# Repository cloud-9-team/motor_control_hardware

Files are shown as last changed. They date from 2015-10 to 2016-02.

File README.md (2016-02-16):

# Control de motores por comunicación Wi-Fi

Este proyecto forma parte de la cátedra de **Taller de Proyecto 1**, perteneciente al segundo semestre de la carrera de Ingeniería en Computación, en la Facultad de Ingeniería de la Universidad de La Plata. 

Nuestra motivación principal es lograr el **control de motores utilizando un tipo de comunicación inalámbrica**. La elección de dicha comunicación debe ser tal que se logre una abstracción del dispositivo desde el cual se envien los comandos de control. 
A partir de estas restricciones elegimos realizar el control de motores de corriente continua mediante el uso del protocolo de comunicación inalámbrica IEEE 802.11, comúnmente conocido cómo Wi-Fi. Al poder abstraernos del dispositivo que envía los comandos, se podrá hacer uso de **smartphones**, **servidores web**, o cualquier otro tipo de dispositivo que cuente con un protocolo de comunicación Wi-Fi integrado.

### Descripción 
En este proyecto se buscará desarrollar específicamente los siguientes puntos:
 - Control de dos motores de corriente continua a través de señales PWM utilizando un H-bridge IC L293D.
 - Comunicación mediante protocolo Wi-Fi con módulo independiente ESP8266.
 - Comunicación serie entre EDU-CIAA y módulo Wi-Fi.
 - Aplicación Android para comunicación con el módulo.

Estos dos últimos ítems se encuentran alojados en el siguiente repositorio https://github.com/cloud-9-team/motor_control_firmware_apps

### Esquema de funcionamiento
El funcionamiento del vehículo será controlado por **instrucciones AT** enviadas inalámbricamente por Wi-Fi desde un smartphone, corriendo un sistema operativo Android, al módulo ESP8266. El módulo ESP8266 enviará las instrucciones por **comunicación serie** a la EDU CIAA-NXP. La EDU CIAA procesará los comandos y, en base a eso, modificará los valores correspondientes de los cuatro outputs de SCT (módulo State Controlled Timer). Las señales serán enviadas a los inputs del H-bridge IC. El H-bridge, en base a la tensión media que reciba por sus entradas, permitirá a los dos motores girar en determinado sentido y con una cierta velocidad. Los sentidos y velocidades de los motores determinarán la dirección de movimiento del vehículo.

### Herramientas de desarrollo
Para el diseño del hardware se utiliza la herramienta de diseño asistido por computadora **Kicad**, y para el desarrollo del software el plugin de la CIAA para el entorno **Eclipse**.

### Integrantes del grupo

 - Julián Ailán
 - Federico Bouche
 - Lucas Hourquebie
 - Emiliano Liotta

### Descarga de los documentos
Debes tener **Git** instalado en tu máquina para poder gestionar las descargas. La instalación de Git depende del sistema operativo que uses
 - Distribuciones de Linux: 
    - En el caso de utilizar Fedora podes utilizar **yum**:
    ```sh
    $ sudo yum install git
    ```
    - En el caso de utilizar distribuciones basadas en Debian tenés que usar **apt-get**:
    ```sh
    $ sudo apt-get install git
    ```
 - Windows: accedé a http://git-scm.com/download/win y la instalación comenzará de forma automática.
 - MacOS: del mismo modo que en Windows, accedé a http://git-scm.com/download/mac y el instalador comenzará a descargarse.

Crear o posicionarse en la carpeta donde se desea descargar el contenido e inicializarla:
```sh
$ mkdir <nombre_de_la_carpeta>
$ cd <nombre_de_la_carpeta>
$ git init
```
Luego se debe relacionar el repositorio con la carpeta donde previamente te situaste:
```sh
$ git remote add origin https://github.com/cloud-9-team/motor_control_hardware.git
```
Por último, los contenidos se descargarán a la carpeta corriendo el siguiente comando:
```sh
$ git pull origin master
```
### Version
1.1

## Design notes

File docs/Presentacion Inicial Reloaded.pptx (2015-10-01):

## Presentación de Informe Inicial

Taller de Proyecto I - E0306

Control de motores mediante comunicación Wi-Fi

Fecha: 28/09/2015 Grupo 1
Integrantes:
Ailan, Julian 515/0 Bouche, Federico 536/5
Hourquebie, Lucas 509/2 Liotta, Emiliano 501/3

## Propuesta Descripción del proyecto Dispositivos a utilizar Diagrama en bloque del sistema Explicación funcional Cronograma

Contenido

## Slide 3

Propuesta

Nuestra motivación principal es lograr el control de motores utilizando un tipo de comunicación inalámbrica. La elección de dicha comunicación debe ser tal que se logre una abstracción del dispositivo desde el cual se envien los comandos de control.
A partir de estas restricciones elegimos realizar el control de motores de corriente continua mediante el uso del protocolo de comunicación inalámbrica IEEE 802.11, comúnmente conocido cómo Wi-Fi.

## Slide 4

Objetivos

Planteamos como objetivo principal el control de dos motores de corriente continua usando una aplicación en un smartphone. Se busca que dichos motores tenga anexadas una rueda cada uno, de modo tal de simular un vehículo a control remoto.
Al poder abstraernos del dispositivo que envía los comandos, esta idea puede escalarse al uso de un servidor web para el caso en que no se cuente con un smartphone.

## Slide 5

Descripción del proyecto

- Control de dos motores de corriente continua a través de señales PWM utilizando un H-bridge IC L293D.
- Comunicación mediante protocolo Wi-Fi con módulo independiente ESP8266.
- Comunicación serie entre EDU-CIAA y módulo Wi-Fi.
- Aplicación Android para comunicación con el módulo.

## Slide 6

Dispositivos a Utilizar

DISPOSITIVO | PROVEEDOR | PRECIO
Placa EDU CIAA-NXP | Electrocomponentes S.A. | $550,00
Módulo Wi-Fi ESP8266 de Espressif | Microelectrónica | $284,00
H-bridge IC L293D de ST Microelectronics | SyC Semiconductores y Componentes | $41,49
Motores CC de 9 volts | - | -

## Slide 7

Dispositivos a Utilizar

Módulo Wi-Fi ESP8266

- Frecuencia de 80 MHz.
- Arquitectura RISC.
- Funciona bajo el protocolo IEEE 802.11 a un frecuencia de 2.4 GHz con soporte WPA/WPA2.
- Presenta módulos GPIO, I²C, ADC, SPI y PWM.
- 64 KB de RAM de instrucciones.
- RAM de 96 KBytes.
- Stack de protocolos TCP/IP integrado.
- Rango de operación desde -40°C hasta 125°C

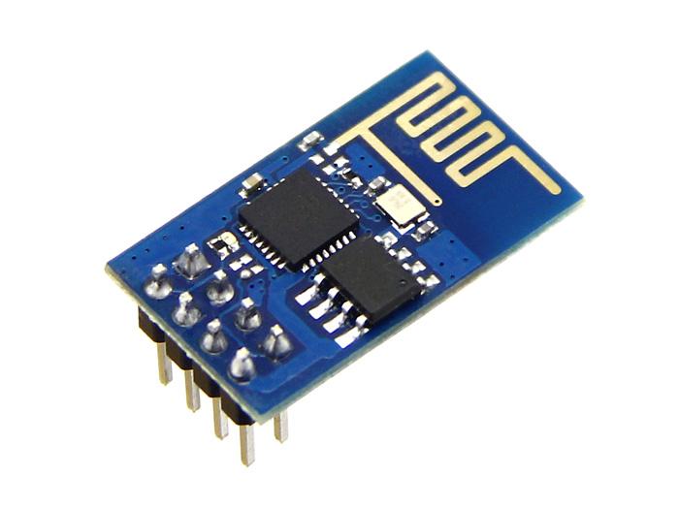
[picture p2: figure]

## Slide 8

Dispositivos a Utilizar

H-bridge IC L293D

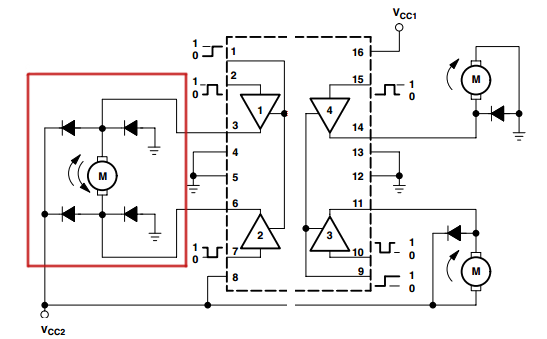
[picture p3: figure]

Configuración utilizada

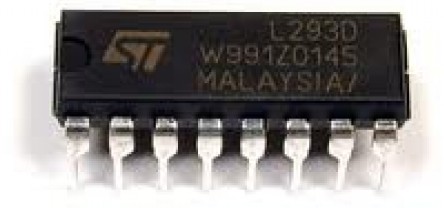
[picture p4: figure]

- Corriente de salida de 600 mA por canal (1.2 A máximo).
- Protección de sobretemperatura
- “0” lógico con tensiones hasta 1.5 V.
- “1” lógico con tensiones desde 2.3 V.
- Diodos de protección integrados.

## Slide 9

Diagrama de BLoques

L293D

ESP8266

MOTOR
1

MOTOR
2

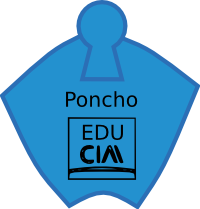
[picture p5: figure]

Transmisor

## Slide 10

Explicación funcional

- El funcionamiento del vehículo será controlado por instrucciones AT enviadas inalámbricamente por Wi-Fi desde un teléfono Android al módulo ESP8266.
- El módulo ESP8266 enviará las instrucciones por comunicación serie a la EDU CIAA-NXP.
- La CIAA procesará los comandos y, en base a eso, modificará los valores correspondientes de los cuatro outputs de SCT (módulo State Controlled Timer).
- Las señales serán enviadas a los inputs del H-bridge IC.
- El H-bridge, en base a la tensión media que reciba por sus entradas, permitirá a los dos motores girar en determinado sentido y con una cierta velocidad.
- Los sentidos y velocidades de los motores determinarán la dirección de movimiento del vehículo.

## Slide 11

Cronograma de Trabajo

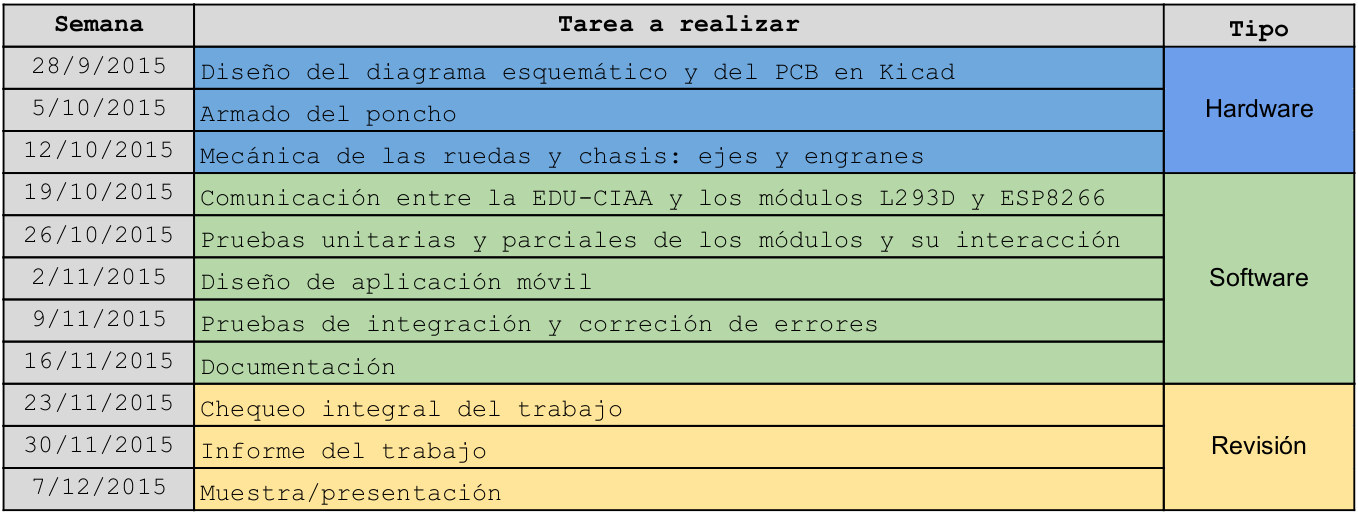
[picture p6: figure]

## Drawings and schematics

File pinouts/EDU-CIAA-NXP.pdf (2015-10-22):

# ASIGNACIÓN DE PINES

# Pernia

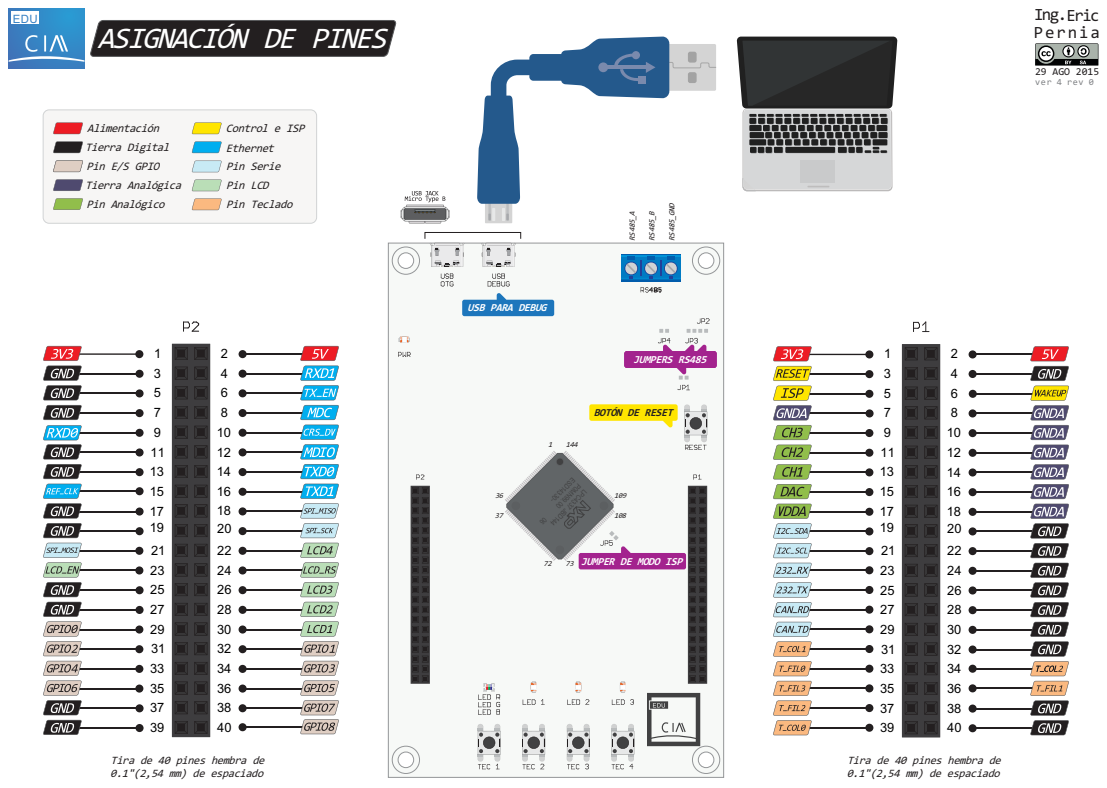
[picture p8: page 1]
Alimentación; Tierra Digital; Pin Analógico; Tierra Analógica; Pin E/S GPIO; Pin Serie; Control e ISP; Pin LCD; Pin Teclado; Ethernet; EDU; LPC4337 JBD144; ESD14330-; JUMPER DE MODO ISP; 29 AGO 2015 ver 4 rev 0; Ing.Eric; JUMPERS RS485; RS485_GND

USB PARA DEBUG

BOTÓN DE RESET

Tira de 40 pines hembra de
0.1"(2,54 mm) de espaciado

# PINES UTILIZADOS DEL NXP LPC4337 JBD144

# Pernia

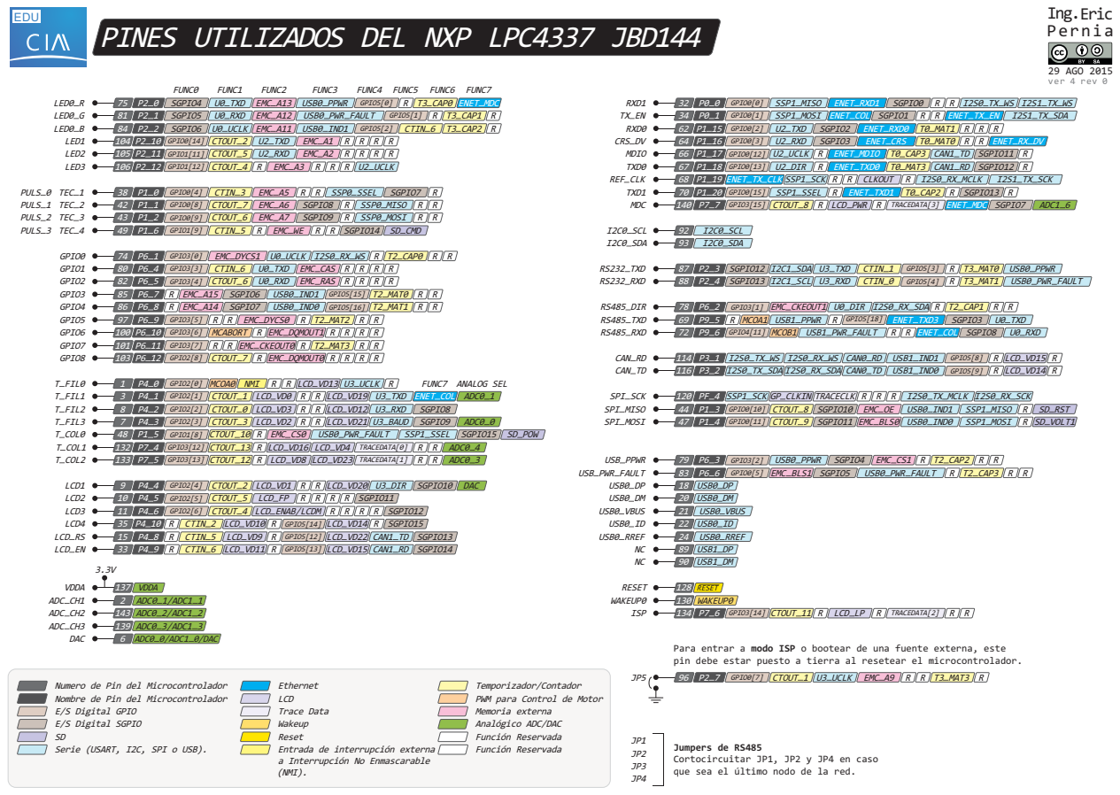
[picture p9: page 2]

Para entrar a modo ISP o bootear de una fuente externa, este
pin debe estar puesto a tierra al resetear el microcontrolador.

Numero de Pin del Microcontrolador
Nombre de Pin del Microcontrolador
E/S Digital GPIO
E/S Digital SGPIO
Serie (USART, I2C, SPI o USB).

Temporizador/Contador
PWM para Control de Motor
Memoria externa
Analógico ADC/DAC
Función Reservada

Jumpers de RS485
Cortocircuitar JP1, JP2 y JP4 en caso
que sea el último nodo de la red.

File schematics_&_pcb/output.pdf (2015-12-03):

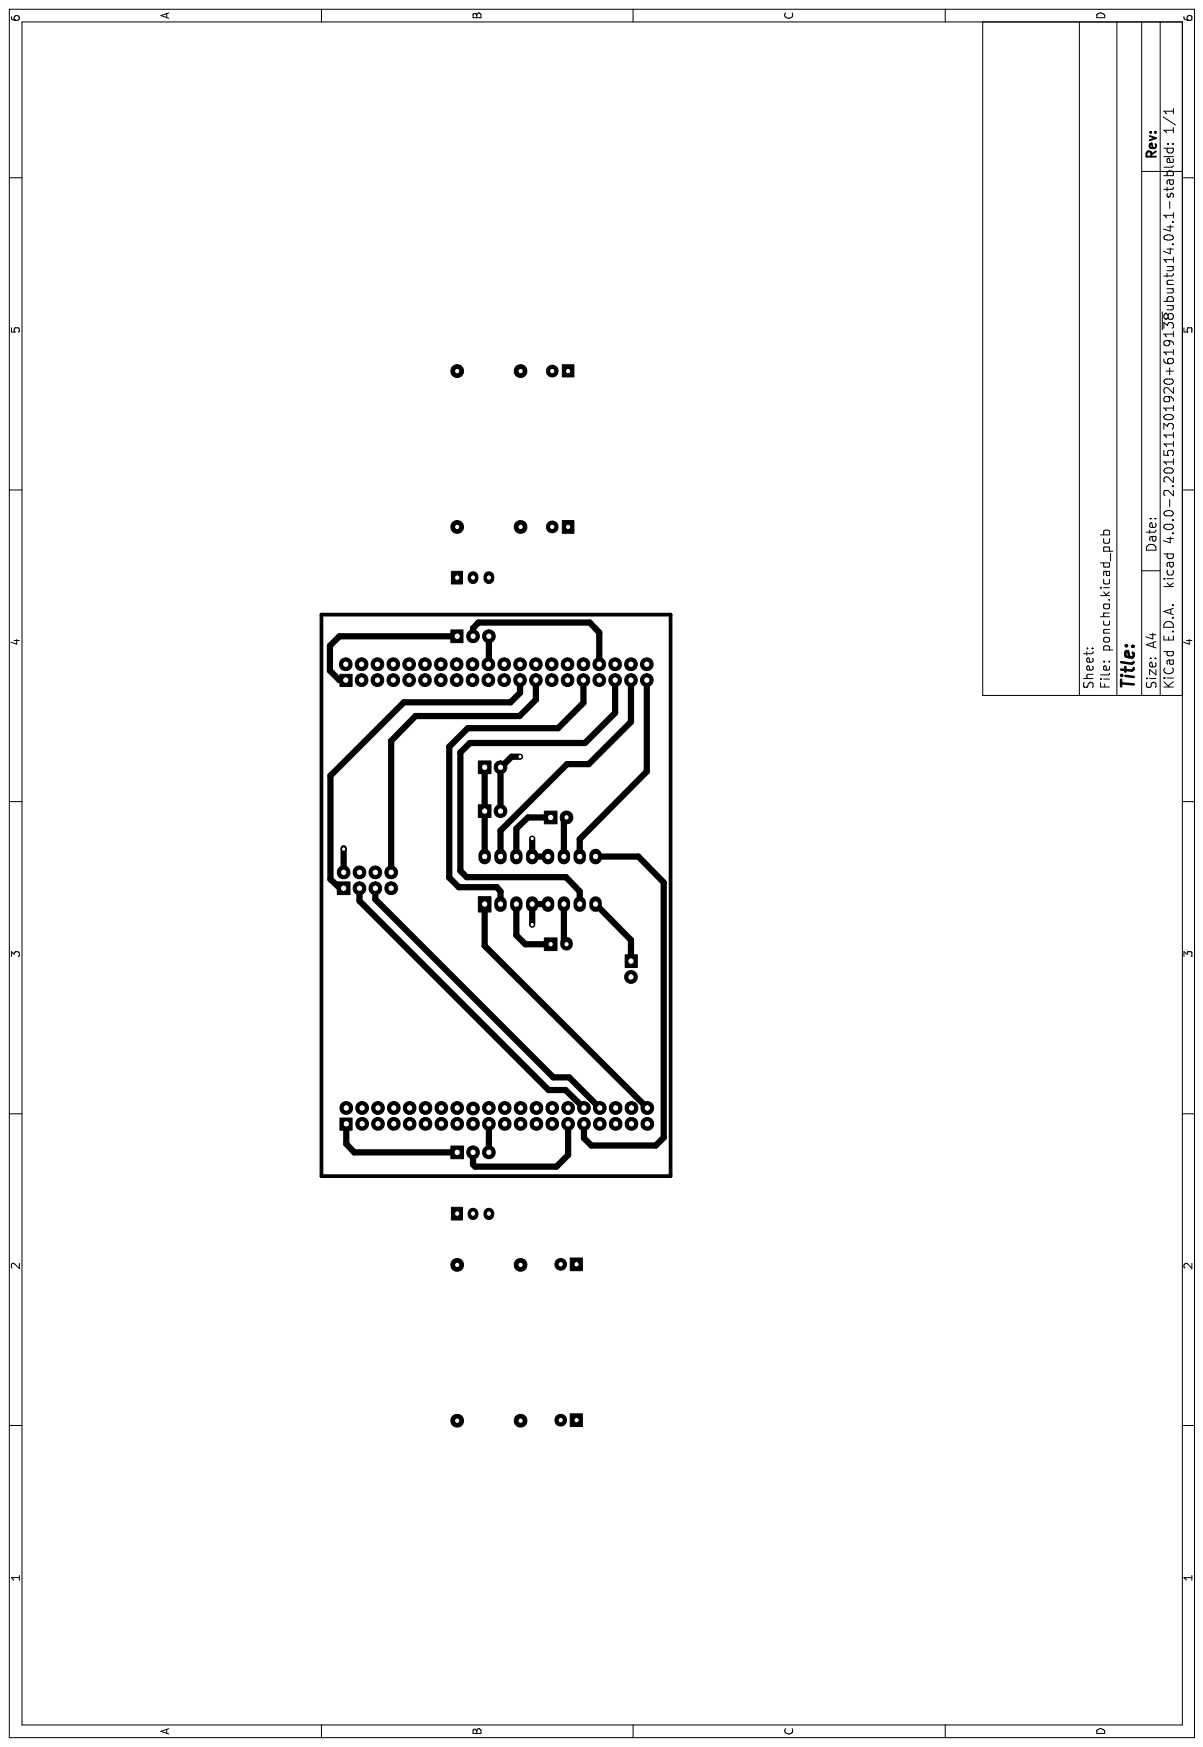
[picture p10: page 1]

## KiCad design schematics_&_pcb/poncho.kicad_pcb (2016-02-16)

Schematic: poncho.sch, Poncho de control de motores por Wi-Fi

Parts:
7805111: LM7805reg; LM7805
C1: CP; Elko_vert_11.2x6.3mm_RM2.5
C2, C3: C; C_Disc_D3_P2.5
C4: CP; c_elec_6.3x4.5
D3, D4: LED; LED-3MM
J1, J2, J3, J8, J9: TB_1X2; bornera1x2
J4, J5, J6, J7: TB_1X3; bornera1x3
L293D1: L293D; DIP-16_W7.62mm_LongPads
P1, P2: CONN_20X2; Pin_Header_Straight_2x20
P3: ESP8266; Pin_Header_Straight_2x04
R1, R4: 180; Resistor_Horizontal_RM10mm
R2, R7: 1k; Resistor_Horizontal_RM10mm
R3, R8: 680; Resistor_Horizontal_RM10mm
R5, R6: R; Resistor_Horizontal_RM10mm
SW1: 6pin_switch
TCST1, TCST2: TCST2103

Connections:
+3V3: C3.1, C4.1, J4.1, J5.1, J6.1, J7.1, P1.1, P2.1, P3.4, R1.1, R2.2, R4.1, R5.2, R7.2; also elsewhere on the board
+5V: C1.1, C2.1, L293D1.16 (VCC1), P1.2, P2.2
/ADC0_1: P1.13
/ADC0_2: P1.11
/ADC0_3: P1.9
/CAN_RD: P1.27
/CAN_TD: P1.29
/DAC: P1.15
/ENET_CRS_DV: P2.10
/ENET_MDC: P2.8
/ENET_MDIO: P2.12
/ENET_REF_CLK: P2.15
/ENET_RXD0: P2.9
/ENET_RXD1: P2.4
/ENET_TXD0: P2.14
/ENET_TXD1: P2.16
/ENET_TX_EN: P2.6
/ENG0_OUT0: J1.1, L293D1.3 (1Y)
/ENG0_OUT1: J1.2, L293D1.6 (2Y)
/ENG1_OUT0: J2.1, L293D1.14 (4Y)
/ENG1_OUT1: J2.2, L293D1.11 (3Y)
/GPIO0: J4.2, J6.2, P2.29, R3.1, TCST1.3; also elsewhere on the board
/GPIO1: P2.32, P3.2
/GPIO2: P2.31, R6.2
/GPIO3: P2.34, P3.3
/GPIO4: P2.33
/GPIO5: P2.36, P3.7
/GPIO6: L293D1.9 (3,4EN), P2.35
/GPIO7: P2.38, P3.6
/GPIO8: L293D1.1 (1,2EN), P2.40
/I2C_SCL: P1.21
/I2C_SDA: P1.19
/ISP: P1.5
/LCD1: P2.30
/LCD2: P2.28
/LCD3: P2.26
/LCD4: P2.22
/LCD_EN: P2.23
/LCD_RS: P2.24
/MOTOR_VCC: J3.1, L293D1.8 (VCC2)
/RESET: P1.3
/RS232_RXD: P1.23, P3.1
/RS232_TXD: P1.25, P3.5
/SPI_MISO: P2.18
/SPI_MOSI: P2.21
/SPI_SCK: P2.20
/TEC_COL0: L293D1.10 (3A), P1.39
/TEC_COL1: L293D1.2 (1A), P1.31
/TEC_COL2: J5.2, J7.2, P1.34, R8.1, TCST2.3
/TEC_F0: P1.33
/TEC_F1: P1.36
/TEC_F2: L293D1.15 (4A), P1.37
/TEC_F3: L293D1.7 (2A), P1.35
/VDD_A: P1.17
/WAKEUP: P1.6
GND: C1.2, C2.2, C3.2, C4.2, D3.1, D4.1, J3.2, J4.3, J5.3, J6.3, J7.3, L293D1.4 (GND1), L293D1.5 (GND2), L293D1.12 (GND4), L293D1.13 (GND3), P1.4, P1.20, P1.22, P1.24, P1.26, P1.28, P1.30, P1.32, P1.38, P1.40, P2.3, P2.5, P2.7, P2.11, P2.13, P2.17, P2.19, P2.25, P2.27, P2.37, P2.39, P3.8, TCST1.2, TCST1.4, TCST2.2, TCST2.4; also elsewhere on the board
GNDA: P1.7, P1.8, P1.10, P1.12, P1.14, P1.16, P1.18
unnamed: J8.2, J9.2
unnamed: D3.2, R5.1
unnamed: D4.2, R6.1
unnamed: J9.1, SW1.2
unnamed 66: R1.2, TCST1.1; also elsewhere on the board
unnamed 67: R2.1, R3.2; also elsewhere on the board
unnamed: R4.2, TCST2.1
unnamed: R7.1, R8.2

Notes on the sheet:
Como los encoders no formarán parte del poncho en sí, sino que se deben poner en algún lugar solidario al eje de cada motor, se deben conectar del siguiente modo: Pin #1: tensión de alimentación 3.3V, Pin #2: señal de salida, Pin #3: tierra.
Alimentación
Recepción

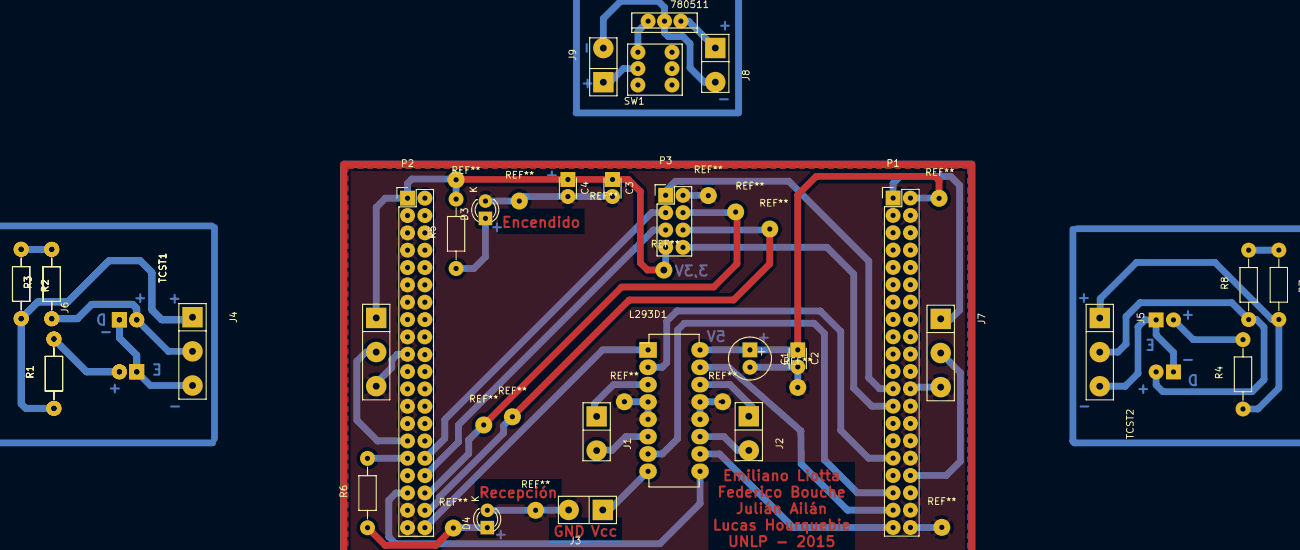
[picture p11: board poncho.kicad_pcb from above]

Board: 2 copper layers, 35 parts (0 on the bottom side), 32 nets.

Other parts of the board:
780511: LM7805reg; LM7805
R1#2: 180; Resistor_Horizontal_RM10mm
R2#2: 1k; Resistor_Horizontal_RM10mm
R3#2: 680; Resistor_Horizontal_RM10mm
TCST1#2: TCST2103

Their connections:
+3V3: R1#2.1, R2#2.2; also elsewhere on the board
/GPIO0: R3#2.1, TCST1#2.3; also elsewhere on the board
GND: TCST1#2.2, TCST1#2.4; also elsewhere on the board
unnamed 66: R1#2.2, TCST1#2.1; also elsewhere on the board
unnamed 67: R2#2.1, R3#2.2; also elsewhere on the board

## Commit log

2015-10-01 Documentos de esquematicos del poncho sin terminar agregados.
    [Cronograma de trabajo.xlsx, file560ACABD.sch, poncho.sch]
2015-10-01 Cambios en el README.md
2015-10-03 Se agregaron modificaciones en los labels del .sch. [TODO] Averiguar como relacionar los resistores con su footprint correspontiente.
    [poncho.sch]
2015-10-05 Esquemático parcialmente terminado. [TODO] PCB.
    [poncho.kicad_pcb, poncho.sch]
2015-10-06 Esquemático terminado. Poncho agregado. [TODO] Corregir eventuales errores. Chequear que estén bien.
    [poncho.dsn, poncho.kicad_pcb]
2015-10-09 Diagrama esquemático y PCB finalizados. [TODO] Verificar que sean correctos.
    [file560ACABD.sch, poncho.dsn, poncho.kicad_pcb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]
2015-10-09 Agregada aplicación Android para la comunicación TCP con módulo ESP8266
2015-10-22 Primer código integral para el control de motores.
2015-10-22 Agregados pinouts de componentes utilizados
2015-10-22 Correciones en el PCB: tamaño de las coronas, pads para vias, ancho de los tracks.
    [poncho.kicad_pcb]
2015-10-22 Agregado código fuente de aplicación Android para la comunicación TCP con el poncho
2015-10-22 Agregada comprimido de aplicación Android
2015-11-10 PCB modificado. [TODO] Verificar que esté correcto y proceder a armar la placa.
    [poncho.kicad_pcb, poncho.sch]
2015-11-12 .pcb y .sch modificados.
    [poncho.kicad_pcb, poncho.sch]
2015-11-21 Modificación del footprint del ESP8266, posición y conexión de los encoders.
    [poncho.kicad_pcb]
2015-12-03 Poncho modificado a dos capas.
    [poncho.dsn, poncho.kicad_pcb, poncho.sch]
2015-12-03 Alimentación del módulo Wi-Fi corregida en PCB.
    [poncho.kicad_pcb]
2015-12-29 Pines de la capa superior corregidos, cambio GPIO2 a GPIO6 para L293D, diodos agregados para alimentación y recepción, encoders con TCST2103 agregados, boton de encendido y regulador agregados.
    [poncho.kicad_pcb, poncho.sch]
2015-12-29 Borneras agregadas.
    [poncho.kicad_pcb, poncho.sch]
2015-12-30 Circuito de encendido modificado. Se invirtió el orden regulador/interruptor.
    [poncho.kicad_pcb, poncho.sch]
2016-02-09 Versión final del PCB.
    [poncho.kicad_pcb, poncho.sch]
2016-02-16 Corrección de warnings y rótulos. La aplicación Android se movió al repositorio de SW.
    [poncho.kicad_pcb, poncho.sch]
